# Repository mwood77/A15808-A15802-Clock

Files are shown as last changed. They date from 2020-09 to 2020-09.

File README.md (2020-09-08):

# A15808 / A15802 Clock modules

> This project is a backup/translation of reference material found at: [http://7400.me/2020/04/04/driving-A15808-clock/](http://7400.me/2020/04/04/driving-A15808-clock/), and additional information I've found during my search for information.

This project aims to have a functional A15802/A15808 as a "desk clock." These are the timing/GMT modules found in McDonnel Douglas / Boeing aircraft between the 70s-90s (guessing) and typically found in 737/747/DC-10 aircraft.

Generally, these timing modules are made by a number of companies, including:
* Haydon (sometimes refered to as **A.W. Haydon**)
* Airpax (unconfirmed)
* HSI (unkown - out of business?)
* Jager (B757 & B767)

Some possible alternate part numbers include:
* 60B00303-1
* A15586
* A15808-P2
* A15589
* WHS102
* 65807-010-1
* A15802-P1
* AP11
* A15592
* A15586B1
* A15802P1

### Electro-mechanical alternatie (A15551)
This is an earlier semi-mechanical model. The requirements needed to run these models are more-or-less the same, but alternatively, you can run these by purchasing an external timing module from Haydon (part number E31814-P1).

## Replacement parts / consumables:
* Aviation connector (milspec) part number:
    * MS27034H12B12PN
* Illumination bulbs - 5V @ 115mA
    * 4x part: WI-7041

## Connector definitions and signal descriptions
> Credit to [7400.me](7400.me) for this section

#### Pinout
| PIN | A15802 & A15808 |  A15551  |
|---|:---:|---:|
| 1  | Lamp | Lamp |
| 2  | Lamp/Shell | Lamp/Shell |
| 3  | +28 volt | +28 volt |
| 4  | Ground | Ground |
| 5  | Lamp/Shell | Lamp/Shell |
| 6  | 60Hz | 60Hz Phase 1 |
| 7  | NC (not connected?) | 60Hz Phase 2 |
| 8  | Chronometer_i01 | Start / Stop switch (n0) |
| 9  | Internal Ground | Chronometer relay |
| 10  | Chronometer_i02 | Start / Stop switch (NC (not connected?)) |
| 11  | Display dimmer | NC (not connected?) |
| 12  | ??? measures @ 10 volt | NC (not connected?) |

#### Description
* Lamp powers the dial lighting bulb, using 4 WI-7041, voltage is 5V, single bulb current 115mA
* Lamp/Shell is the other pole of the bulb, which is also connected to the case for grounding. It is worth noting that the lighting power supply and housing are completely isolated from the electronic part of the clock.
* The range of +28V power input is actually very wide, and the measured clock can still run normally around 15V.
* I copied the circuit behind the 60Hz clock signal input, and found that the two clocks are connected to a transistor through a resistor divider after passing the DC blocking capacitor, and then amplified for use in the subsequent circuit. According to estimation and actual measurement, the 5V level can make the circuit work normally.
* For A15551, if you want the stopwatch to work normally, you need to short-circuit pins 8-9 or 9-10. Among them, the 8/10 pin is internally connected to the button that controls the stopwatch on the panel. The button is self-locking. Press the pin 8 to connect the power supply, and press the pin 10 to connect the power supply. Pin 9 is internally connected to a time relay that controls the operation/reset of the stopwatch.
* For the A15808, the control of the stopwatch is more complicated. The following is the signal processing circuit copied out.
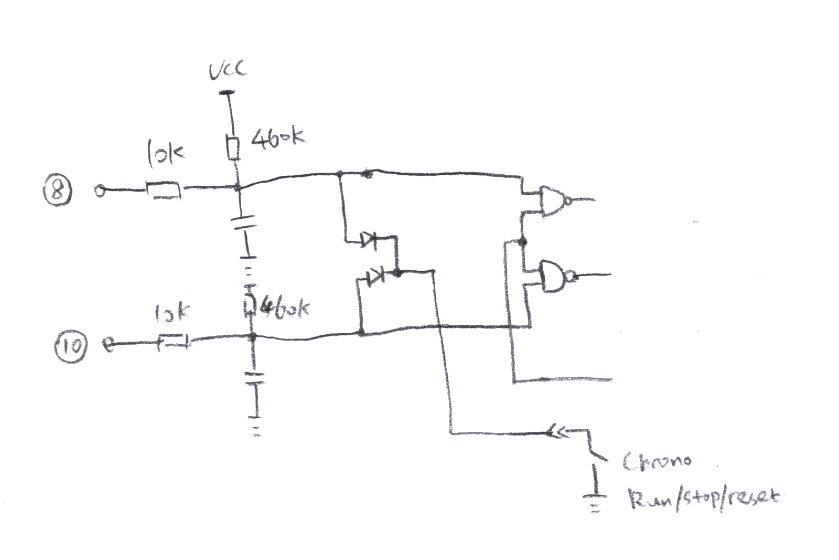
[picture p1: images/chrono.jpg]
chronometer signal processing circuit

Among them, the 8th and 10th pins are each connected to a NAND gate, and also connected to the RUN/STOP/RESET button on the panel through two diodes. Press the button, the two signal lines are pulled down at the same time, thereby controlling the subsequent stopwatch logic.
When any one of pins 8 and 10 is pulled low from the outside (shorted to pin 9), it will also trigger the stopwatch action. But if the trigger is the 8th foot, pulling down the 8th again will not have any effect, and the stopwatch will continue to run until the 10th foot is pulled down and the stopwatch stops. At this time, pin 10 loses its function again, and pin 8 needs to be pulled down to trigger the stopwatch reset. In the same way, if pin 10 is triggered at the beginning, then pin 8/10 needs to be triggered sequentially to complete the stop and reset operations.
For such a strange control logic, I am not clear about its function. However, a general guess is that on a Boeing 747, the pilot/co-pilot and pilot have a clock. Maybe their clocks 8/9/10 signal lines are connected in parallel, so that the stopwatches of the three can be synchronized, and it is convenient for the three people to work together.
* For A15802/A15808, pin 11 can control the brightness of the filament display tube. 0-5V is the darkest (extinguished) and brightest respectively. I also try to use PWM drive, which can also achieve the control purpose.

### Pinout images
##### A15808
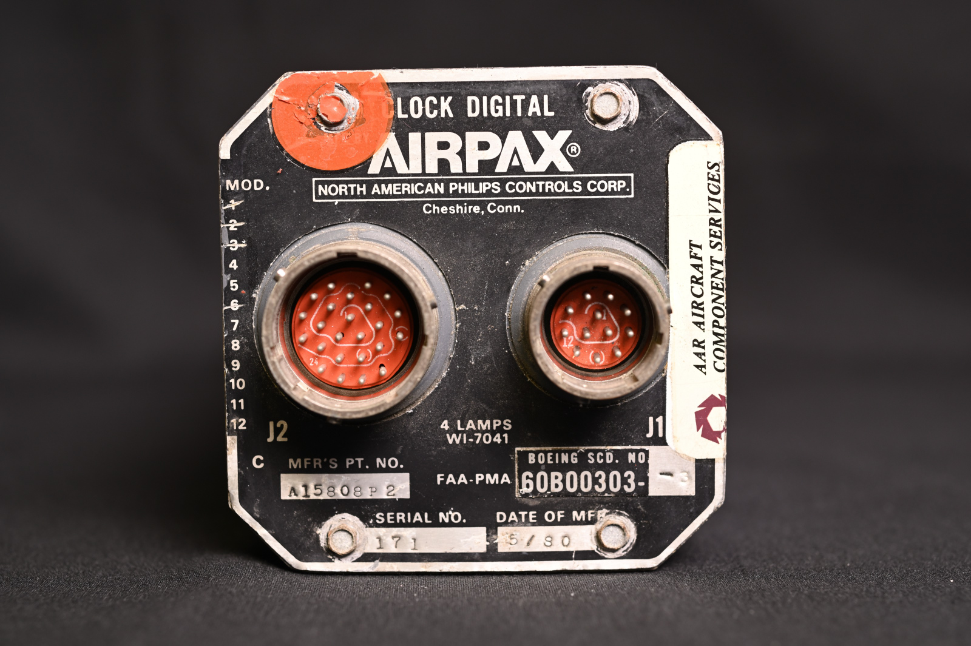
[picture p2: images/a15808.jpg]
A15808 back


##### A15551
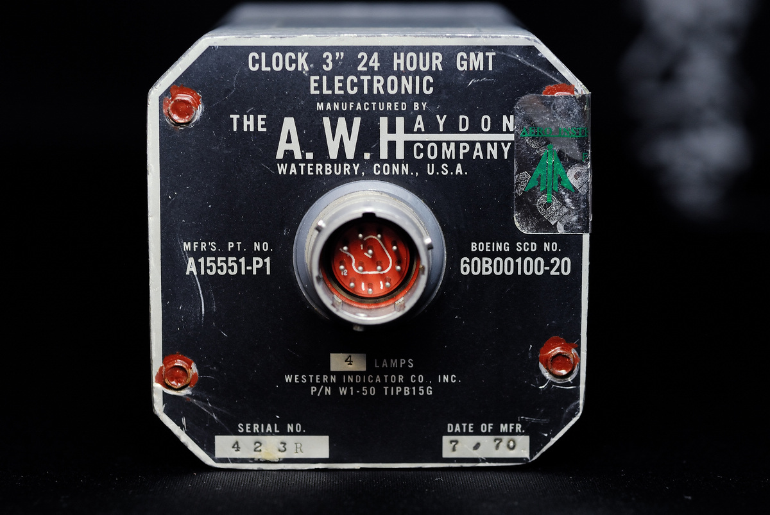
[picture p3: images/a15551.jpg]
A15551 back


## Driving the clock(s)
See the attached folders:
* `ClockDriver_board` for board information
* `ClockDriver_attin214` for code
    * Attiny214 uses the latest UPDI single-wire protocol to download, and the download tool recommends pyupdi @ 
https://github.com/mraardvark/pyupdi

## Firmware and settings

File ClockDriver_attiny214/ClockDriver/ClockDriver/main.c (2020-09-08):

/*
 * ClockDriver.c
 *
 * Created: 2020/3/7 23:49:53
 * Author : lhf
 */

 /****Attiny214 Pinout********
           --------
          |o       |
      VDD-|1     14|-GND
      PA4-|2     13|-PA3/EXTCLK
      PA5-|3     12|-PA2
      PA6-|4     11|-PA1
      PA7-|5     10|-PA0/RESET/UPDI
TOSC1/PB3-|6      9|-PB0
TOSC2/PB2-|7      8|-PB1
          |        |
	       --------
******************************/

/**********Pin mapping*********
PA0		UPDI
PA1		RX8025_SDA
PA2		RX8025_SCL
PA3		32.768KHz input
PA4		PWM for dimming (TCA0_WO4)
PA5		PWM for backlight (TCA0_WO5)
PA6		CDS sensor input (ADC6)
PA7		Potential meter input (ADC7)

PB0		Phase1 output
PB1		Phase2 output
PB2		LED         
PB3		Button      
 ******************************/

 /*********Interrupts**********
 PA3 Rising edge	32.768KHz interrupt
 TCA				1000Hz control interrupt
 ******************************/


#include <avr/io.h>
#include <avr/interrupt.h>
#include "peripherals.h"

#define PH1_ON() PORTB_OUTSET = 0b00000001
#define PH1_OFF() PORTB_OUTCLR = 0b00000001
#define PH2_ON() PORTB_OUTSET = 0b00000010
#define PH2_OFF() PORTB_OUTCLR = 0b00000010

#define LED_ON() PORTB_OUTSET = 0b00000100
#define LED_OFF() PORTB_OUTCLR = 0b00000100
#define LED_TOGGLE() PORTB_OUTTGL = 0b00000100

#define BUTTON (!(PORTB_IN & 0b00001000))


volatile uint8_t light_value = 0;
volatile uint8_t pot_value = 0;
uint16_t light_value_filtered = 0;
uint16_t pot_value_filtered = 0; // 256 times the actual value

uint8_t pwm_backlight = 0;
uint8_t pwm_dimming = 0;
uint16_t pwm_dimming_auto = 0;
uint16_t pwm_backlight_filtered = 0;
uint16_t pwm_dimming_filtered = 0;

uint8_t backlight_enable = 0;
uint8_t auto_dimming_enable = 0;

volatile uint16_t tick_cnt = 0;
volatile uint8_t pps_flag = 0;

uint8_t button_cnt = 0;

void delay_ms(uint16_t ms)
{
	tick_cnt = 0;
	while(tick_cnt < ms)asm("nop");
	tick_cnt = 0;
}

uint8_t read_eeprom(uint8_t address)
{
	return *((uint8_t*)EEPROM_START + address);
}

void write_eeprom(uint8_t address, uint8_t data)
{
	*((uint8_t*)EEPROM_START + address) = data;
	asm("cli");
	CCP = 0x9d;//Unlock self-programming
	NVMCTRL_CTRLA = 0x03;//Erase & write to EEPROM
	asm("sei");
	while(NVMCTRL_STATUS & 0x02)asm("nop");//Wait till finish
}

int main(void)
{
	PORTA_DIR = 0b00110110;
	PORTA_OUT = 0b10000000;

	PORTB_DIR = 0b00000111;
	PORTB_PIN3CTRL = 0b00001000;//Enable pull up on PB3
	PORTB_OUT = 0b00000000;
	PORTA_PIN3CTRL = 0b00000010;//32.768K interrupt, enable rising edge interrupt

	init_clk(CLK_SRC_OSC20M, CLK_DIV1);
	init_adc();
	init_tca0();

	backlight_enable = read_eeprom(0);
	auto_dimming_enable = read_eeprom(1);
	asm("sei");
    while (1) 
    {
		if(tick_cnt >= 12)//~100Hz
		{
			tick_cnt = 0;

			//Read keys
			if(!BUTTON && (button_cnt>=5) && (button_cnt < 200))//Short press, switch backlight
			{
				backlight_enable = !backlight_enable;
				write_eeprom(0, backlight_enable);
			}			
			if(button_cnt==200)//Long press, switch auto-dimming
			{
				auto_dimming_enable = !auto_dimming_enable;
				write_eeprom(1, auto_dimming_enable);
				if(auto_dimming_enable)//Flash twice
				{
					LED_ON();
					delay_ms(250);
					LED_OFF();
					delay_ms(250);
					LED_ON();
					delay_ms(250);
					LED_OFF();
					delay_ms(250);
				}
				else//Flash once
				{
					LED_ON();
					delay_ms(500);
					LED_OFF();
					delay_ms(500);
				}
			}
			button_cnt = BUTTON?((button_cnt < 255)?(button_cnt+1):255):0;

			//Dimming control
			pot_value_filtered = pot_value_filtered - (pot_value_filtered >> 4) + (pot_value << 4);
			light_value_filtered = light_value_filtered - (light_value_filtered >> 8) + light_value;

			if(auto_dimming_enable)
			{
				pwm_dimming_auto = (light_value_filtered >> 8) * (pot_value_filtered >> 8);
				pwm_dimming_auto >>= 7;
				if(pwm_dimming_auto < 30)pwm_dimming = 30;
				else if(pwm_dimming_auto > 255)pwm_dimming = 255;
				else pwm_dimming = (uint8_t)pwm_dimming_auto;
				pwm_backlight = backlight_enable?pwm_dimming:0;				
			}
			else
			{
				pwm_dimming = (uint8_t)(pot_value_filtered >> 8);
				if(pwm_dimming < 30)pwm_dimming = 30;
				pwm_backlight = backlight_enable?pwm_dimming:0;
			}

			pwm_backlight_filtered = pwm_backlight_filtered - (pwm_backlight_filtered >> 5) + (pwm_backlight << 3);
			pwm_dimming_filtered = pwm_dimming_filtered - (pwm_dimming_filtered >> 5) + (pwm_dimming << 3);

			//Flash LED
			if(pps_flag)
			{
				LED_ON();
				pps_flag = 0;
			}
			else
			{
				LED_OFF();
			}

			//Output PWM
			TCA0_SPLIT_HCMP1 =(uint8_t)(pwm_dimming_filtered >> 8);//Dimming
			TCA0_SPLIT_HCMP2 = 255 - (uint8_t)(pwm_backlight_filtered >> 8);//PWM for backlight is inversed

			ADC0_MUXPOS = 0x06;
			ADC0_COMMAND = 0x01;//Start reading sensors
		}
    }
}

uint8_t counter_dropper = 0;
uint8_t counter_divider = 0;
uint8_t  out_state = 0;
uint16_t pps_divider = 0;
//32768Hz interrupt
ISR(PORTA_PORT_vect)
{
	if(PORTA_INTFLAGS & 0b00001000)
	{
		//32768/(60Hz*4)=136...128
		//So we drop 1 clock every 32768/128=256 clocks
		if(counter_dropper == 255)counter_dropper = 0;
		else
		{
			counter_dropper++;
			if(counter_divider>= 135)
			{
				counter_divider = 0;
				out_state = out_state <= 2?(out_state + 1):0;
				switch(out_state)
				{
					case 0:
					PH1_ON();
					PH2_OFF();
					break;
					case 1:
					PH1_ON();
					PH2_ON();
					break;
					case 2:
					PH1_OFF();
					PH2_ON();
					break;
					case 3:
					PH1_OFF();
					PH2_OFF();
					break;
					default:break;
				}
			}
			else
			{
				counter_divider++;
			}
			if(pps_divider < 32767)
				pps_divider++;
			else
			{
				pps_divider = 0;
				pps_flag = 1;
			}
		}
	}
	PORTA_INTFLAGS |= 0xff;
}

//1220Hz period
ISR(TCA0_HUNF_vect)
{
	tick_cnt++;
	TCA0_SPLIT_INTFLAGS |= 0xff;
}

ISR(ADC0_RESRDY_vect)
{
	if(ADC0_MUXPOS == 0x06)//CDS value has been read
	{
		pot_value = 255 - ADC0_RESL;
		ADC0_MUXPOS = 0x07;//Read Pot value in the next cycle
		ADC0_COMMAND = 0x01;//Start next conversion
	}
	else
	{
		light_value = ADC0_RESL;
		ADC0_MUXPOS = 0x06;//Read CDS in the next cycle
	}
}

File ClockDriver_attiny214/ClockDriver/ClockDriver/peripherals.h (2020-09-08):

#ifndef __PERIPHERALS_H
#define __PERIPHERALS_H

#define CLK_SRC_OSC20M		0x00
#define CLK_SRC_OSCULP32K	0x01
#define CLK_SRC_XOSC32K		0x02
#define CLK_SRC_EXTCLK		0x03

#define CLK_DIV1	0x00
#define CLK_DIV2	0x01
#define CLK_DIV4	0x03
#define CLK_DIV8	0x05
#define CLK_DIV16	0x07
#define CLK_DIV32	0x09
#define CLK_DIV64	0x0b
#define CLK_DIV6	0x11
#define CLK_DIV10	0x13
#define CLK_DIV12	0x15
#define CLK_DIV24	0x17
#define CLK_DIV48	0x19
inline void init_clk(uint8_t source, uint8_t divider)
{
	CCP = 0xd8;
	CLKCTRL_MCLKCTRLA = source;
	CCP = 0xd8;//Unlock protected I/O registers
	CLKCTRL_MCLKCTRLB = divider;
}

inline void init_tca0()
{
	TCA0_SPLIT_CTRLA = 0b00001011;//DIV64 enabled, freq = 20M/64/256=1220Hz
	TCA0_SPLIT_CTRLB = 0b01100000;//Enable high-byte compare 1 & 2 (WO4 & WO5)
	TCA0_SPLIT_CTRLC = 0b00000000;
	TCA0_SPLIT_CTRLD = 0b00000001;//Enable split mode
	TCA0_SPLIT_INTCTRL = 0b00000010;//Enable HUNF interrupt

	TCA0_SPLIT_HPER = 255;//Only use higher half for PWM & periodic interrupt
	TCA0_SPLIT_LPER = 0;

	TCA0_SPLIT_HCMP1 = 100; //Dimming PWM
	TCA0_SPLIT_HCMP2 = 100; //Backlight PWM

}

inline void init_adc()
{
	ADC0_CTRLA = 0b00000101;//Enable ADC, 8bit mode
	ADC0_CTRLB = 0b00000000;//No accumulation
	ADC0_CTRLC = 0b01010100;//Select VDD as reference, CLK=DIV32
	ADC0_CTRLD = 0b00110000;//InitDelay = 16 CLKADC, enable ASDV
	ADC0_CTRLE = 0b00000000;//Disable Window comparator
	ADC0_SAMPCTRL = 0b00000000;//Sample length is 2 CLKADC
	ADC0_EVCTRL = 0b00000000;//No event used
	ADC0_INTCTRL = 0b00000001;//Result ready interrupt

	ADC0_MUXPOS = 0x06;//select CDS as default
}

#endif

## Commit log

2020-09-08 first draft
    [ClockController.PrjPcb, clock_controller.PcbDoc, clock_controller.PcbLib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]
2020-09-15 added archives of board and driver
